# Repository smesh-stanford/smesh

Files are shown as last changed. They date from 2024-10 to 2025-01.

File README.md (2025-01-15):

# What is SMesh?
___
SMesh is a sensor mesh network ("smesh") that performs long duration environmental sensing for sustainability research at Stanford.

A smesh node (or "snode") consists of a sensor payload plus a Meshtastic board that can relay readings using long range LoRa radio.

# Customizing Meshtastic firmware
___
Snodes run a stable version of Meshtastic firmware with small modifications.

To access this firmware:
1. Clone the firmware fork, i.e. `git clone https://github.com/josdo/meshtastic-firmware.git`
2. Follow https://meshtastic.org/docs/development/firmware/build/ to set up PlatformIO, a tool to build firmware from source. 
   **Note:** at step 3, pick `heltec-v3` from the list of options given.

# SMesh - Raspberry Pi Setup Guide
___

## Install Raspberry Pi OS on SD Card

1. Go to: [Raspberry Pi Software](https://www.raspberrypi.com/software/)
2. Download and install **Raspberry Pi Imager**.
3. Insert your SD card into your computer or laptop.
4. Open **Raspberry Pi Imager**.
5. Click on the **CHOOSE OS** box, then select:
    - `Raspberry Pi OS (other)`
    - Scroll down and select: `Raspberry Pi OS (Legacy, 32-bit) Lite`
6. Click on the **CHOOSE STORAGE** box and select your SD card.
7. Click on the **Settings** icon in the bottom right corner, then follow the steps:
    - Set hostname to `smeshX` (where X represents the number of the current system).
    - Tick the **Enable SSH** box.
    - Set the username and password:
      - Username: `pi`
      - Password: `smesh`
    - Configure wireless LAN:
      - SSID: Name of your WiFi network
      - Password: Password of your WiFi network
      - Wireless LAN country: `US`
    - Click **SAVE**.
8. Click **WRITE** to begin writing the OS to the SD card.
9. Once the Raspberry Pi OS has been installed, remove the SD card from your computer and insert it into your Raspberry Pi.
10. Power the Raspberry Pi by connecting a micro USB cable to the **PWR IN** slot (connected to a battery pack or wall outlet).
11. A green LED should light up near the **PWR IN** slot to indicate that the Raspberry Pi is ON.

## Remotely Connect to Raspberry Pi via SSH

1. After a couple of minutes, the Raspberry Pi should be connected to your local WiFi network.
2. Ensure your computer/laptop is connected to the same network.
3. Open a Terminal and enter the command:
   ```
   ssh pi@smeshX.local
   ```
4. During the first SSH connection, you may get the following error:
5. If you see this error:
    - Go to your user folder on your computer/laptop.
    - Find a folder named `.ssh`.
    - Open the file named `known_hosts` and delete its content, then save.
    - Try connecting again with:
      ```
      ssh pi@smeshX.local
      ```
6. When asked "*Are you sure you want to continue connecting?*", enter: `yes`.
7. Enter the password: `smesh`.
8. Once you see the prompt starting with `pi@smeshX`, you have successfully connected to the Raspberry Pi via SSH.

## Install Software and Dependencies on Raspberry Pi

1. Once connected via SSH, start by running the following commands:
    ```
    sudo apt update
    sudo apt upgrade
    ```
2. Install Python **pip**:
    ```
    sudo apt install python3-pip
    ```
3. Install **Git**:
    ```
    sudo apt install git -y
    ```
4. Clone the project's GitHub repository:
    ```
    git clone https://github.com/smesh-stanford/smesh.git
    ```
5. Open a different Terminal and upload the `credential.json` file from your own local directory to the Raspberry Pi by entering the command:
    ```
    scp /local/path/to/credentials.json pi@smeshX.local: /home/pi/smesh/snode
    ```
    (e.g. if the credentials.json file is stored in your local Downloads directory: `scp ~/Downloads/credentials.json pi@smeshX.local: /home/pi/smesh/snode` , where X in smeshX represents the number of the current system).
6. Once the upload has been completed, close this Terminal and go back to the previous one (where the SSH connection to the Raspberry Pi was established).
7. Navigate to the `snode` directory:
    ```
    cd ./smesh/snode
    ```
8. Install required dependencies:
    ```
    pip3 install -r requirements.txt
    ```
9. Create a data directory:
    ```
    mkdir data
    ```
10. In its default stage, the code will store any upcoming data packet to this data directory (absolute path: `/home/pi/smesh/snode/data`). In some cases, the user may want to change the name of the data directory to help with data management. In such case, the path to the data directory needs to be changed in the **read_aqi.py, start_read_aqi.sh** and **upload_to_gdrive.py** scripts located in `/smesh/snode/scripts`:
    - **read_aqi.py:** From line 46 - 76, all the path arguments in the **log_to_csv()** function need to be changed to the new data directory path. For instance, if the user created a different data directory named *data_pepperwood*, all path arugments in the log_to_csv() function would be changed to: `f’/home/pi/smesh/snode/**data_pepperwood**/{nodeid}_bme688.csv’`
    - **start_read_aqi.sh:** Line 7, Change the path in the last line from `~/smesh/snode/**data**/read_aqi_stdouterr_log.txt` to the new data directory path (e.g., `~/smesh/snode/**data_pepperwood**/read_aqi_stdouterr_log.txt`)
    - **uploading_to_gdrive.py:** Change the path in ****Line 33 in the main function, to the new data directory path (e.g. `'/home/pi/smesh/snode/**data_pepperwood'**`)
11. Give execute permissions to the script **start_read_aqi.sh**:
    ```
    chmod +x ~/smesh/snode/scripts/start_read_aqi.sh
    ```
12. Open the cron table editor:
    ```
    crontab -e
    ```
13. Enter `1` to select the **nano** text editor.
14. Scroll to the bottom and add the following two lines (the number `5` in the second line indicates the time in minutes between uploads):
    ```
    @reboot ~/smesh/snode/scripts/start_read_aqi.sh
    */5 * * * * /usr/bin/python3 ~/smesh/snode/scripts/upload_to_gdrive.py
    ```
15. Press `Ctrl + X` to exit.
16. Type `Y` and press `Enter` to save changes.
17. Run the command:
    ```
    python3 read_aqi.py /dev/ttyUSB0
    ```
18. The Cron Unix-based job scheduler should now be active, running the `read_aqi.py` and `upload_to_gdrive.py` scripts to upload data to Google Drive.

## Troubleshooting Tips

- Restart the Cron Unix-based job scheduler:
  ```
  sudo service cron restart
  ```
- Check the status of the Cron Unix-based job scheduler:
  ```
  systemctl status cron
  ```

- Test the `read_aqi.py` script for errors:
  1. Navigate to the script directory:
     ```
     cd ~/smesh/snode/scripts/
     ```
  2. Run the script without providing a serial port:
     ```
     python3 read_aqi.py
     ```
  3. If the only error shown is similar to the following, it means all dependencies are correctly installed:
  4. Next, run the script with the USB0 port:
     ```
     python3 read_aqi.py /dev/ttyUSB0
     ```
  5. If you get an error indicating that the port cannot be found, reconnect the Meshtastic or reboot the Raspberry Pi:
     ```
     reboot
     ```
  6. After reboot, reconnect via SSH:
     ```
     ssh pi@smeshX.local
     ```
  7. Enter the password: `smesh`.

# Contributing
*Cutting Releases*
Releases will be formatted as "XX.YY.ZZ" with the following scheme: 
- XX: major feature release, breaking changes
- YY: minor feature change, new functions or classes 
- ZZ: patches, bug fixes, optimizations

*Pushing commits*
Create a new branch following "task/feature-name", "bug/bug-name" and so forth

A recommended workflow would be:
```
git stash
git checkout main
git pull
git checkout (your branch)
git stash pop
git rebase origin/main
Fix merge conflicts
git push —force-with-lease
```

Prior to merging a PR, be sure to squash your commits. One way to do this is to run `git rebase -i` and replace everything but the first commit message with `s` for squash as so:
```
pick abc123 Commit message 1
s def456 Commit message 2
s ghi789 Commit message 3
```

*Notes for Contributions*
- Before starting on some new big chunk of code, it it is optional but highly recommended to open an issue first
  to say "Hey, I think this idea X should be implemented and I'm starting work on it. My general plan is Y, any feedback
  is appreciated." This will allow other devs to potentially save you time by not accidentially duplicating work etc...
- Please do not check in files that don't have real changes
- Please do not reformat lines that you didn't have to change the code on
- We recommend using the [Visual Studio Code](https://platformio.org/install/ide?install=vscode) editor along with the ['Trunk Check' extension](https://marketplace.visualstudio.com/items?itemName=trunk.io) (In beta for windows, WSL2 for the linux version),
  because it automatically follows our indentation rules and its auto reformatting will not cause spurious changes to lines.
- If your PR fixes a bug, mention "fixes #bugnum" somewhere in your pull request description.
- If your other co-developers have comments on your PR please tweak as needed.
- Please also enable "Allow edits by maintainers".
- If your PR gets accepted you can request a "Contributor" role in the Meshtastic Discord

# Usage (depreciated)
___
`snode` is a Python package that contains all dependencies and code to read from snodes.

Files are organized into three directories:
1. One-off scripts go into `snode/scripts`
2. Reusable code that scripts can import go into `snode/snode`
3. Tests for reusable code go into `snode/tests`

To run any Python code:
1. Install Poetry by following https://python-poetry.org/docs/#installing-with-pipx
2. Enter the package you're using, e.g., `cd snode`
3. Install the Python dependencies the code needs, i.e., `poetry install`
4. Run a Python script, i.e., `poetry run python PATH/TO/SCRIPT.PY`

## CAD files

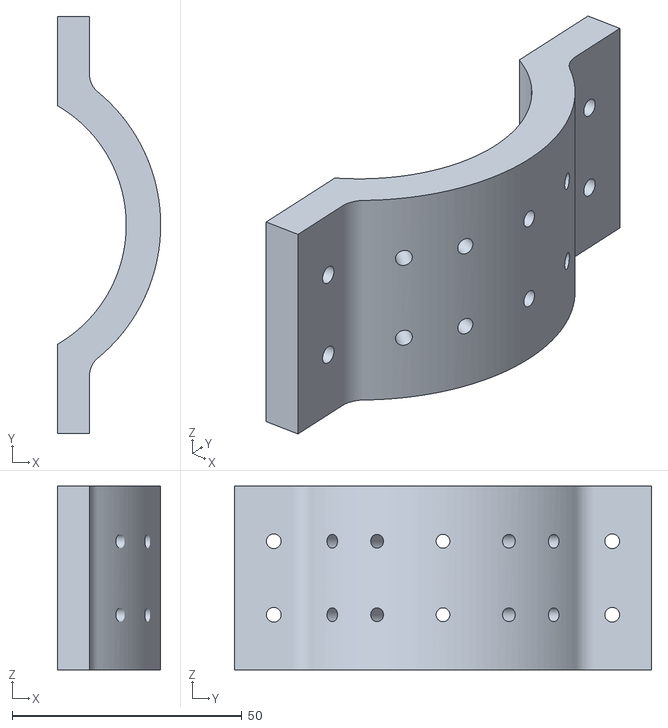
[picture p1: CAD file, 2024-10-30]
physical/mechanical/5.2-dome_and_holder/v5.2 - Enclosure only - Part 2.stl
22.5 x 90.7 x 40.0

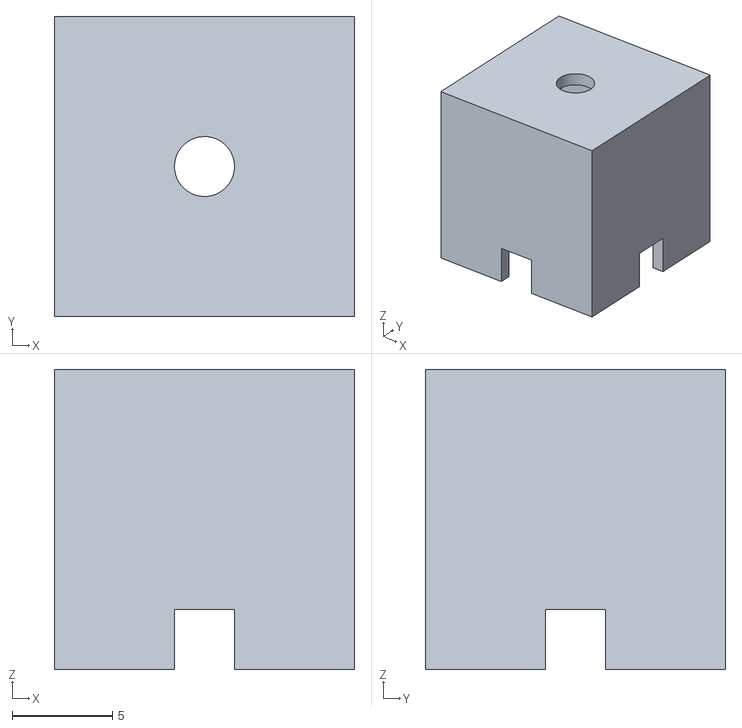
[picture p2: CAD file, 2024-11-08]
physical/mechanical/antennaholder.stl
15.0 x 15.0 x 15.0

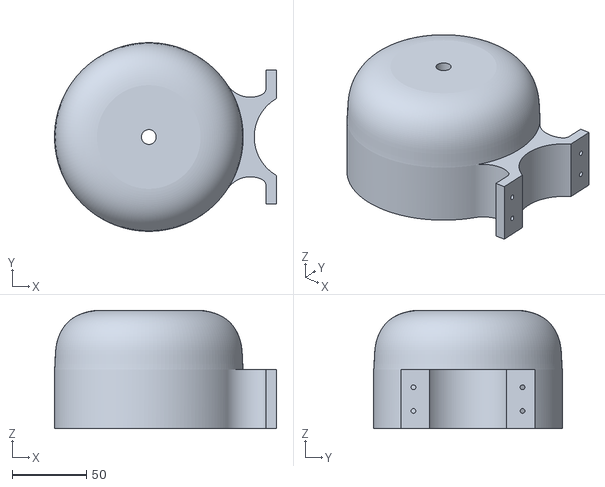
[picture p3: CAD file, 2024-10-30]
physical/mechanical/5.2-dome_and_holder/v5.2 - Enclosure only - Part 1.stl
149.9 x 127.4 x 80.0

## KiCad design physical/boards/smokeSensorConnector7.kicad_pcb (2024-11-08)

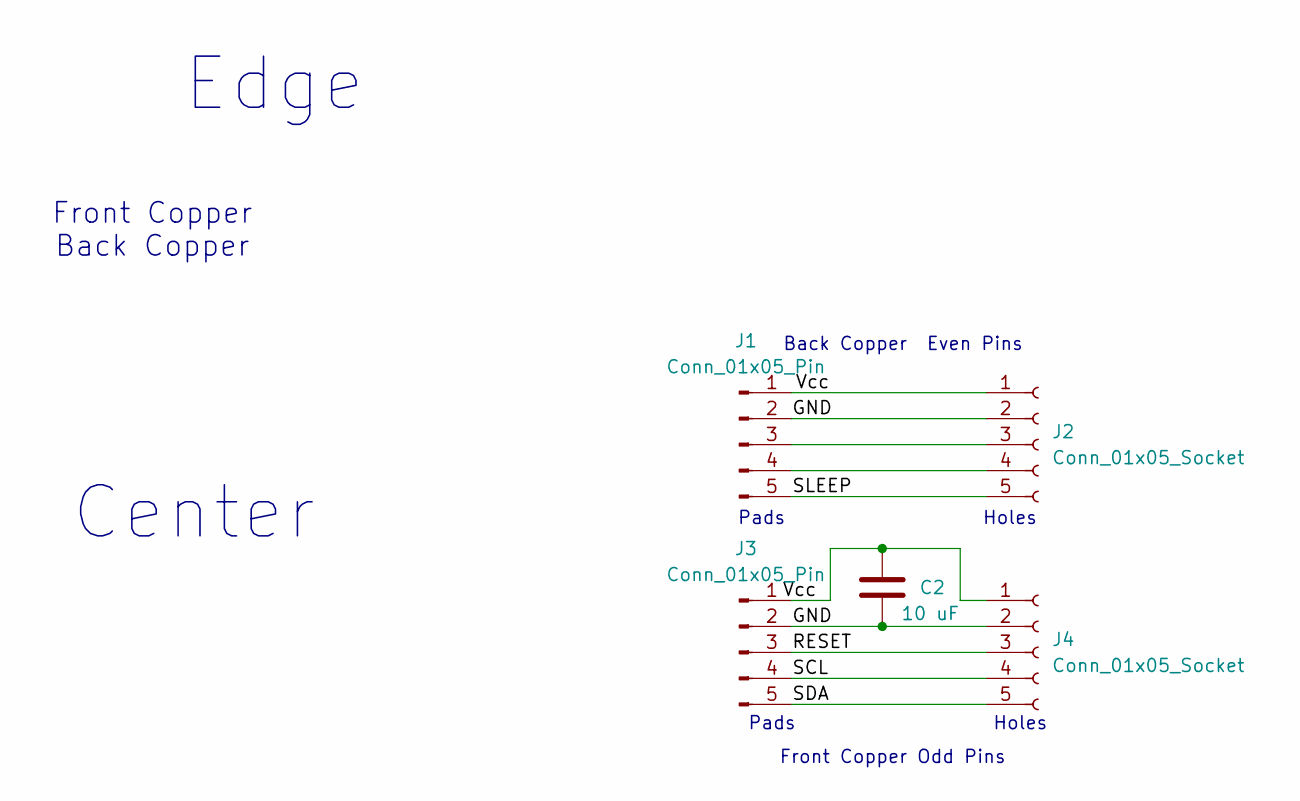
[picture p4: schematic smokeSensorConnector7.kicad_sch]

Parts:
C2: 10 uF; C_0805_2012Metric_Pad1.18x1.45mm_HandSolder
J1, J3: Conn_01x05_Pin; PinHeader_2x05_P1.00mm_Vertical_SMD
J2, J4: Conn_01x05_Socket; PinSocket_1x05_P2.54mm_Vertical

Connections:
/GND: C2.2, J1.2, J2.2, J3.2, J4.2
/RESET: J3.3, J4.3
/SCL: J3.4, J4.4
/SDA: J3.5, J4.5
/SLEEP: J1.5, J2.5
/Vcc: C2.1, J1.1, J2.1, J3.1, J4.1
unnamed: J1.3, J2.3
unnamed: J1.4, J2.4

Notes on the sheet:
Front Copper Back Copper
Center
Front Copper Odd Pins
Back Copper Even Pins
Pads Holes
Edge

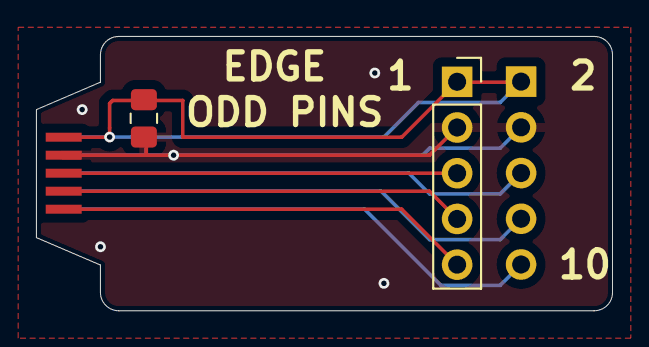
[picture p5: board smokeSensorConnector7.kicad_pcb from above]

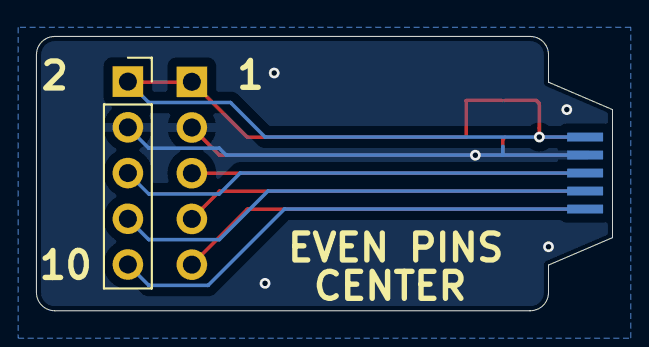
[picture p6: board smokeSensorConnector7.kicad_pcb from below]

Board: 2 copper layers, 32.0 x 15.2 mm, 5 parts (2 on the bottom side), 8 nets.

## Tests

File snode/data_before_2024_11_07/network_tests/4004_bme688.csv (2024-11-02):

2024-11-02 09:38:59.974664 | 0x336918e8 | 24.975153 | 40.520565 | 1011.9683 | 145.57863 | 227 | 7.0 | 5 | -65 | 5
2024-11-02 09:39:03.388706 | 0x433efcb4 | 25.741278 | 36.38869 | 1011.4799 | 676.77515 | 106 | 5.75 | 3 | -67 | 3
2024-11-02 09:39:06.332685 | 0x4358fbec | 27.327984 | 33.633705 | 1011.6007 | 446.09018 | 88 | 5.25 | 6 | -79 | 6
2024-11-02 09:39:20.301704 | 0x336918e8 | 24.970427 | 40.521217 | 1011.967 | 144.96036 | 226 | 6.0 | 5 | -69 | 5
2024-11-02 09:39:24.892501 | 0x433efcb4 | 25.711206 | 36.434563 | 1011.4597 | 671.3446 | 106 | 5.5 | 3 | -69 | 3
2024-11-02 09:39:27.791551 | 0x4358fbec | 27.33014 | 33.686333 | 1011.58966 | 452.2968 | 82 | -0.5 | 6 | -90 | 6
2024-11-02 09:39:41.247261 | 0x336918e8 | 24.986933 | 40.43119 | 1011.96765 | 146.32751 | 224 | 5.5 | 5 | -69 | 5
2024-11-02 09:39:46.342864 | 0x4358fbec | 27.337856 | 33.654846 | 1011.60394 | 452.89694 | 83 | 4.75 | 6 | -79 | 6
2024-11-02 09:39:58.002227 | 0x433efcb4 | 25.603674 | 36.604164 | 1011.44507 | 666.66394 | 108 | 5.75 | 3 | -63 | 3
2024-11-02 09:40:01.026133 | 0x336918e8 | 25.001318 | 40.382744 | 1011.9892 | 148.23393 | 222 | 5.75 | 5 | -67 | 5
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

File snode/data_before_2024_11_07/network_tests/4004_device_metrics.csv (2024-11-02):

2024-11-02 09:38:54.542882 | 0x4358fbec | 101 | 4.239 | 24.126667 | 6.0195556 | 6.25 | 6 | -71 | 6
2024-11-02 09:39:35.419871 | 0x33644004 | 101 | 4.209 | 21.33 | 0.051333338 |  | 6 |  | 6
2024-11-02 09:40:31.146955 | 0x433efcb4 | 101 | 4.236 | 21.776667 | 5.756778 | 5.5 | 3 | -70 | 3
2024-11-02 09:40:35.449356 | 0x33644004 | 101 | 4.215 | 20.761667 | 0.11272222 |  | 6
2024-11-02 09:41:29.808206 | 0x336918e8 | 101 | 5.14 | 22.278332 | 3.3621664 | 5.0 | 5 | -74 | 5
2024-11-02 09:41:33.518703 | 0x433efcb4 | 100 | 4.19 | 22.965 | 5.756778 | 5.5 | 3 | -64 | 3
2024-11-02 09:41:35.576283 | 0x33644004 | 101 | 4.232 | 21.786667 | 0.14400001 |  | 6
2024-11-02 09:42:35.574146 | 0x33644004 | 101 | 4.204 | 30.596668 | 0.27727777 |  | 6
2024-11-02 09:43:34.235770 | 0x433efcb4 | 100 | 4.197 | 23.966667 | 5.678 | 5.5 | 3 | -71 | 3
2024-11-02 09:43:35.708284 | 0x33644004 | 101 | 4.236 | 29.716667 | 0.32155555 |  | 6
2024-11-02 09:44:35.569759 | 0x43590ff4 | 100 | 4.199 | 23.83 | 5.544083 | 5.25 | 5 | -74 | 5
2024-11-02 09:44:35.840091 | 0x33644004 | 101 | 4.213 | 28.906668 | 0.4722222 |  | 6
2024-11-02 09:45:35.682924 | 0x33644004 | 101 | 4.22 | 37.41333 | 0.5910278 |  | 6
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

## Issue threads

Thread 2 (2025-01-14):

Separate `Dashboard` and `Physical` to new repositories

danineamati, 2025-01-14:
The current `smesh` repo should probably only contain (1) the firmware and (2) the logging software (arguably, even these should be separate repositories). The `dashboard` code should be a separate repository and may benefit from adding https://github.com/smesh-stanford/smesh_visualization as a dependency. The `physical` files (i.e., PCB and 3D printing files) will not interact with the firmware or logging code and can either be a separate repository or just on Google Drive.

lfun1, 2025-01-25:
GitHub Repo Reorganization:
- Transferred dashboard folder to [smesh_dashboard](https://github.com/smesh-stanford/smesh_dashboard) repo
    - Added smesh_visualization as dependency to smesh_dashboard using git submodules
    - See this [Linked Dependency Post](https://stackoverflow.com/questions/7813030/how-can-i-have-linked-dependencies-in-a-git-repo) for instructions on how to update dependencies
        - `git submodule init`, `git submodule update` for your existing dependency version
        - `cd visualization`, `git pull` to update dependency version
- Moved physical folder to Google Drive [physical folder](https://drive.google.com/drive/folders/1TcDmi7lHw6MQ5zjq9wXfqhfcP2IxHO2b?usp=drive_link) in smesh-mechanical folder
- Firmware and logging (snode) kept in original smesh repo

danineamati, 2025-01-29:
Looks great to me! Do you want to include the submodule context in the readme in the `smesh_dashboard` repo?

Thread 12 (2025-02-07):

Notification of Snode Being Down

yumibyte, 2025-02-07:
# CONTEXT
This is an open ended, cute and cool additional feature. It would be interesting to receive a notification (e.g. slack) when a Snode is "down." This downage can be determined by the logs from the snode and also based off of any errors provided in the log (e.g. watchdog timer error).

Some requirements would be:
- Notation of which node is down
- Perhaps a clip of the log which triggered this notification
- Ensuring this notification is not "spammed"

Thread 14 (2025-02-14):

Setup LED to be configured on initialize.sh

yumibyte, 2025-02-14:
# CONTEXT
We want to be able to configure the LED on the Raspberry Pi to display multiple colors via a neopixel for more specific error logging. Talk to Pete! Refer to this document: https://drive.google.com/file/d/1JKwW2ykTD3mngxr49Tp5c5CxWLDgQb8F/view

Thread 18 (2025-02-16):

Adjust firstrun such that initialize_rpi.sh passes parameters and can execute

yumibyte, 2025-02-16:
# CONTEXT
- The current script doesn't function with `firstrun.sh` and appears to not run the `initialize_rpi.sh` script. As a part of this issue we should tackle passing the proper passwords and names to the `initialize_rpi.sh` script. Therefore, this issue tackles how to configure the rpi from the first initialization "all in one go."

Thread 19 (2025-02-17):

Setting the relevant SNode intervals

danineamati, 2025-02-17:
## Background
The Meshtastic configuration is stored in a yaml file, such as https://github.com/smesh-stanford/smesh/blob/main/firmware/build_standard_1.0.yaml. However, some of the intervals are based on (limited) field data, and some are set by default. The intervals for the sensors have been set with some domain knowledge in mind. The most recent settings are in https://github.com/smesh-stanford/smesh/blob/main/firmware/build_1_config.yaml.

## Questions

1. However, the `nodeInfoBroadcastSecs` is set at `10800` by default. What should this be set at and why?
3. Can we better set the sensor intervals using frequency space analysis of the data we already have?

## Helpful references

### Documentation
Documentation information: https://meshtastic.org/docs/overview/mesh-algo/#regular-broadcast-intervals

### Meshtastic Configuration
Command to export the config file from meshtastic device to computer:
```
meshtastic --export-config > example_config.yaml
```
(depending on path, `python -m meshtastic` may be more reliable)

Command to import the config file from computer to meshtastic device:
```
meshtastic --configure example_config.yaml
```

### Example observed field data intervals

Pepperwood:
- Air Quality (60 sec): https://github.com/smesh-stanford/smesh_visualization/blob/main/plots/pepperwood-post-burn/62e4/full_timeseries/pmsa003i_sensor_interval_boxplot_bound_50-70s.png
- Device Metrics (360 sec): https://github.com/smesh-stanford/smesh_visualization/blob/main/plots/pepperwood-post-burn/62e4/full_timeseries/device_metrics_sensor_interval_boxplot_bound_330-390s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
- Environmental (60 sec): https://github.com/smesh-stanford/smesh_visualization/blob/main/plots/pepperwood-post-burn/62e4/full_timeseries/bme688_sensor_interval_boxplot_bound_50-70s.png
- Power (300 sec): https://github.com/smesh-stanford/smesh_visualization/blob/main/plots/pepperwood-post-burn/62e4/full_timeseries/ina260_sensor_interval_boxplot_bound_270-330s.png

Burn Bot (note links point to branch, not main):
- Air Quality (60 sec): https://github.com/smesh-stanford/smesh_visualization/blob/external-data/plots/burnbot-post-burn/4004/full_timeseries/pmsa003i_sensor_interval_boxplot_bound_50-140s.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
- Device Metrics (360 sec): https://github.com/smesh-stanford/smesh_visualization/blob/external-data/plots/burnbot-post-burn/4004/full_timeseries/device_metrics_sensor_interval_boxplot_bound_33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
- Environmental (60 or 180 sec): https://github.com/smesh-stanford/smesh_visualization/blob/external-data/plots/burnbot-post-burn/4004/full_timeseries/bme688_sensor_interval_boxplot_bound_50-200s.pn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
- Power (300 or 600 sec): https://github.com/smesh-stanford/smesh_visualization/blob/external-data/plots/burnbot-post-burn/4004/full_timeseries/ina260_sensor_interval_boxplot_bound_270-630s.p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

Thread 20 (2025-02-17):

Testing the initialize RPi script with hardware in the loop

danineamati, 2025-02-17:
## Context
In PR #17, we added the `initialize_rpi.sh` script to set up the Raspberry Pi as a "SMesh Logger Raspberrry Pi." While we did verify that it works on the software side, there may be some hardware-in-the-loop checks that may be worthwhile to verify before any field deployment.

⚠ _Please document throughout with screenshots and images!_

## Hardware needed for checks
- Real-Time Clock (RTC) with clock battery
- "Normal" Meshtastic Radio
- Mobile device (ideally both iOS and Android devices)
- Laptop with Raspberry Pi Imager
- Presence in Packard

## Code snips separated by Hardware-in-the-loop checks
- [x] Can connect to wifi automatically (e.g., EE-IoT): https://github.com/smesh-stanford/smesh/blob/d5a541cff879ac5890c1ad75927a494ffb5df7c3/snode/scripts/initialize_rpi.sh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
    - Verified 16 Feb from the third-floor bridge over the atrium. **Have we tested this from a fresh Pi Image?**
- [ ] Connects to Real Time Clock: https://github.com/smesh-stanford/smesh/blob/d5a541cff879ac5890c1ad75927a494ffb5df7c3/snode/scripts/initialize_rpi.sh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
- [ ] Verify that the swap is set correctly: https://github.com/smesh-stanford/smesh/blob/d5a541cff879ac5890c1ad75927a494ffb5df7c3/snode/scripts/initialize_rpi.sh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
- [ ] Meshtastic radio gets properly configured: https://github.com/smesh-stanford/smesh/blob/d5a541cff879ac5890c1ad75927a494ffb5df7c3/snode/scripts/initialize_rpi.sh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
- [ ] Commands are correctly added to `cron` and are run at reboot (i.e., rather than immediately): https://github.com/smesh-stanford/smesh/blob/d5a541cff879ac5890c1ad75927a494ffb5df7c3/snode/scripts/initialize_rpi.sh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
- [x] SSH to pi is functional through pi hotspot: https://github.com/smesh-stanford/smesh/blob/d5a541cff879ac5890c1ad75927a494ffb5df7c3/snode/scripts/initialize_rpi.sh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
    - Verified 16 Feb using the Terminus App on Pixel 6a. **Have we tested on an iOS device?**

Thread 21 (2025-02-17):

Add Google Drive upload to cron at initialize

danineamati, 2025-02-17:
### Context
Currently, the `initialize_rpi.sh` script adds the _logging_ to the cron, but it does not add the Google Drive upload to the cron.

https://github.com/smesh-stanford/smesh/blob/d5a541cff879ac5890c1ad75927a494ffb5df7c3/snode/scripts/initialize_rpi.sh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

### Suggested fix
Use the `routine_upload_gdrive.sh` bash script as an example to set up the cron. https://github.com/smesh-stanford/smesh/blob/d5a541cff879ac5890c1ad75927a494ffb5df7c3/snode/scripts/routine_upload_gdrive.sh

⚠ You will need authentication information from Jessica to successfully upload to Google Drive.

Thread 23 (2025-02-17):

Deprecating old logger scripts

danineamati, 2025-02-17:
We have a few scripts that are no longer in use and should be deprecated. We may not want to delete them outright until we have a more reliable logger.

- [ ] 🐍  `log_telemetry.py` (`rpi_log_script.py` is the new version): https://github.com/smesh-stanford/smesh/blob/d5a541cff879ac5890c1ad75927a494ffb5df7c3/snode/scripts/log_telemetry.py
- [ ] 🐍 `network_test.py` (`rpi_log_script.py` is the new version): https://github.com/smesh-stanford/smesh/blob/d5a541cff879ac5890c1ad75927a494ffb5df7c3/snode/scripts/network_test.py
- [ ] 🐍 `read_aqi.py` (`rpi_log_script.py` is the new version): https://github.com/smesh-stanford/smesh/blob/d5a541cff879ac5890c1ad75927a494ffb5df7c3/snode/scripts/read_aqi.py
    - ⚠ `read_aqi.py` is the most reliable logging script thus far and was the only one that seemed to fully work at BurnBot (rationale unclear)
- [ ] 🏗  `start_network_read_aqi.sh` (`initialize_rpi.sh` now sets the python file in cron directly AND `network_test.py` is to be deprecated above): https://github.com/smesh-stanford/smesh/blob/d5a541cff879ac5890c1ad75927a494ffb5df7c3/snode/scripts/start_network_read_aqi.sh
- [ ] 🏗  `start_read_aqi.sh` (`initialize_rpi.sh` now sets the python file in cron directly AND `read_aqi.py` is to be deprecated above): https://github.com/smesh-stanford/smesh/blob/d5a541cff879ac5890c1ad75927a494ffb5df7c3/snode/scripts/start_read_aqi.sh
- [ ] 🏗  `start_rpi_log.sh` (`initialize_rpi.sh` now sets the python file in cron directly): https://github.com/smesh-stanford/smesh/blob/d5a541cff879ac5890c1ad75927a494ffb5df7c3/snode/scripts/start_rpi_log.sh
- [ ] 🏗  `routine_upload_gdrive.sh` (`initialize_rpi.sh` should include this code; see Issue #21): https://github.com/smesh-stanford/smesh/blob/d5a541cff879ac5890c1ad75927a494ffb5df7c3/snode/scripts/routine_upload_gdrive.sh

Remaining scripts (not deprecated):
🔝 signals most recently updated
- 🔝  🐍 `rpi_log_script.py` runs the Python script to log the Meshtastic data: https://github.com/smesh-stanford/smesh/blob/d5a541cff879ac5890c1ad75927a494ffb5df7c3/snode/scripts/rpi_log_script.py
- 🔝 🏗 `initialize_rpi.sh` initializes the Pi and sets the corn: https://github.com/smesh-stanford/smesh/blob/d5a541cff879ac5890c1ad75927a494ffb5df7c3/snode/scripts/initialize_rpi.sh
- 🐍 `serial_log.py` shows everything on the USB serial connection, which is helpful for debugging a new sensor (e.g., the LARK and PAWS wind sensors). https://github.com/smesh-stanford/smesh/blob/d5a541cff879ac5890c1ad75927a494ffb5df7c3/snode/scripts/serial_log.py
- 🏗 `traceroute_test.sh` has an example code for tracing the mesh route, but it needs to be updated; see Issue #22). https://github.com/smesh-stanford/smesh/blob/d5a541cff879ac5890c1ad75927a494ffb5df7c3/snode/scripts/traceroute_test.sh
- 🐍 `upload_to_gdrive.py` runs the python to push the data to Google Drive. https://github.com/smesh-stanford/smesh/blob/d5a541cff879ac5890c1ad75927a494ffb5df7c3/snode/scripts/upload_to_gdrive.py

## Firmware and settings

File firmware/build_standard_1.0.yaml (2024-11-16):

config:
    bluetooth:
        enabled: true
        fixedPin: 336710
        mode: FIXED_PIN
    device:
        nodeInfoBroadcastSecs: 10800
        serialEnabled: true
    display:
        screenOnSecs: 600
    lora:
        channelNum: 104
        frequencyOffset: 0.05
        hopLimit: 5
        region: US
    telemetry:
        airQualityEnabled: true
        airQualityInterval: 30
        deviceUpdateInterval: 360
        environmentMeasurementEnabled: true
        environmentUpdateInterval: 60
        powerMeasurementEnabled: true
        powerUpdateInterval: 300

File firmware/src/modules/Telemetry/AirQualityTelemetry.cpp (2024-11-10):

#include "configuration.h"

#if !MESHTASTIC_EXCLUDE_ENVIRONMENTAL_SENSOR

#include "../mesh/generated/meshtastic/telemetry.pb.h"
#include "AirQualityTelemetry.h"
#include "Default.h"
#include "MeshService.h"
#include "NodeDB.h"
#include "PowerFSM.h"
#include "RTC.h"
#include "Router.h"
#include "detect/ScanI2CTwoWire.h"
#include "main.h"
#include <Throttle.h>

int32_t AirQualityTelemetryModule::runOnce()
{
    /*
        Uncomment the preferences below if you want to use the module
        without having to configure it from the PythonAPI or WebUI.
    */

    moduleConfig.telemetry.air_quality_enabled = 1;
    moduleConfig.telemetry.air_quality_interval = 3;

    if (!(moduleConfig.telemetry.air_quality_enabled)) {
        // If this module is not enabled, and the user doesn't want the display screen don't waste any OSThread time on it
        return disable();
    }

    if (firstTime) {
        // This is the first time the OSThread library has called this function, so do some setup
        firstTime = false;

        if (moduleConfig.telemetry.air_quality_enabled) {     
            LOG_INFO("Air quality Telemetry: Initializing");
            if (!aqi.begin_I2C(&Wire1)) {
                LOG_WARN("Could not establish i2c connection on peripheral bus");
                return disable();
            }
            // Look for the Sensor
            uint8_t i2caddr_scan[] = {PMSA0031_ADDR};
            uint8_t i2caddr_asize = 1;
            auto i2cScanner = std::unique_ptr<ScanI2CTwoWire>(new ScanI2CTwoWire());
            i2cScanner->scanPort(ScanI2C::I2CPort::WIRE1, i2caddr_scan, i2caddr_asize);
            auto found = i2cScanner->find(ScanI2C::DeviceType::PMSA0031);
            if (found.type != ScanI2C::DeviceType::NONE) {
                nodeTelemetrySensorsMap[meshtastic_TelemetrySensorType_PMSA003I].first = found.address.address;
                nodeTelemetrySensorsMap[meshtastic_TelemetrySensorType_PMSA003I].second =
                    i2cScanner->fetchI2CBus(found.address);
                return (1000);
                }
            uint16_t try_again = 1000;
            while (try_again--) {
                LOG_WARN("Could not establish i2c connection to AQI sensor. Rescanning...");
                if (found.type != ScanI2C::DeviceType::NONE) {
                    nodeTelemetrySensorsMap[meshtastic_TelemetrySensorType_PMSA003I].first = found.address.address;
                    nodeTelemetrySensorsMap[meshtastic_TelemetrySensorType_PMSA003I].second =
                        i2cScanner->fetchI2CBus(found.address);
                    return (1000);
                    }
                }
            LOG_WARN("Could not establish i2c connection to AQI sensor.");
            return disable();
        }
        } else {
        // if we somehow got to a second run of this module with measurement disabled, then just wait forever
        if (!moduleConfig.telemetry.air_quality_enabled)
            return disable();

        if (((lastSentToMesh == 0) ||
             !Throttle::isWithinTimespanMs(lastSentToMesh, 3000))){
            //  Default::getConfiguredOrDefaultMsScaled(
            //        moduleConfig.telemetry.air_quality_interval,
            //        default_telemetry_broadcast_interval_secs, numOnlineNodes))) &&
            // airTime->isTxAllowedChannelUtil(config.device.role != meshtastic_Config_DeviceConfig_Role_SENSOR) &&
            // airTime->isTxAllowedAirUtil()) {
            sendTelemetry();
            lastSentToMesh = millis();
        } else if (service->isToPhoneQueueEmpty()) {
            // Just send to phone when it's not our time to send to mesh yet
            // Only send while queue is empty (phone assumed connected)
            sendTelemetry(NODENUM_BROADCAST, true);
        }
    }
    return sendToPhoneIntervalMs;
}

bool AirQualityTelemetryModule::handleReceivedProtobuf(const meshtastic_MeshPacket &mp, meshtastic_Telemetry *t)
{
    if (t->which_variant == meshtastic_Telemetry_air_quality_metrics_tag) {
#ifdef DEBUG_PORT
        const char *sender = getSenderShortName(mp);

        LOG_INFO("(Received from %s): pm10_standard=%i, pm25_standard=%i, pm100_standard=%i", sender,
                 t->variant.air_quality_metrics.pm10_standard, t->variant.air_quality_metrics.pm25_standard,
                 t->variant.air_quality_metrics.pm100_standard);

        LOG_INFO("                  | PM1.0(Environmental)=%i, PM2.5(Environmental)=%i, PM10.0(Environmental)=%i",
                 t->variant.air_quality_metrics.pm10_environmental, t->variant.air_quality_metrics.pm25_environmental,
                 t->variant.air_quality_metrics.pm100_environmental);
#endif
        // release previous packet before occupying a new spot
        if (lastMeasurementPacket != nullptr)
            packetPool.release(lastMeasurementPacket);

        lastMeasurementPacket = packetPool.allocCopy(mp);
    }

    return false; // Let others look at this message also if they want
}

bool AirQualityTelemetryModule::getAirQualityTelemetry(meshtastic_Telemetry *m)
{
    if (!aqi.read(&data)) {
        LOG_WARN("Skipping send measurements. Could not read AQIn");
        return false;
    }

    m->time = getTime();
    m->which_variant = meshtastic_Telemetry_air_quality_metrics_tag;
    m->variant.air_quality_metrics.pm10_standard = data.pm10_standard;
    m->variant.air_quality_metrics.pm25_standard = data.pm25_standard;
    m->variant.air_quality_metrics.pm100_standard = data.pm100_standard;

    m->variant.air_quality_metrics.pm10_environmental = data.pm10_env;
    m->variant.air_quality_metrics.pm25_environmental = data.pm25_env;
    m->variant.air_quality_metrics.pm100_environmental = data.pm100_env;

    LOG_INFO("(Sending): PM1.0(Standard)=%i, PM2.5(Standard)=%i, PM10.0(Standard)=%i",
             m->variant.air_quality_metrics.pm10_standard, m->variant.air_quality_metrics.pm25_standard,
             m->variant.air_quality_metrics.pm100_standard);

    LOG_INFO("         | PM1.0(Environmental)=%i, PM2.5(Environmental)=%i, PM10.0(Environmental)=%i",
             m->variant.air_quality_metrics.pm10_environmental, m->variant.air_quality_metrics.pm25_environmental,
             m->variant.air_quality_metrics.pm100_environmental);

    return true;
}
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

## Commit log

2024-10-30 added dome + holder cad
    [v5.2 - Enclosure only - Part 1.stl, v5.2 - Enclosure only - Part 2.stl]
2024-11-01 4004 logging from afcc range tests 10-31-2024
    [4004_bme688.csv, 4004_device_metrics.csv, 4004_ina260.csv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]
2024-11-02 Network test script and data on 11/2/24
    [4004_bme688.csv, 4004_device_metrics.csv, 4004_ina260.csv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]
2024-11-02 Network test update data
    [4004_bme688.csv, 4004_pmsa003i.csv]
2024-11-05 corrected paths to data directory in read_aqi.py
    [read_aqi.py]
2024-11-06 replaced paths in read_aqi.py with absolute paths
    [read_aqi.py]
2024-11-08 Reorganize GitHub folder structure
    [antennaholder.stl, smokeSensorConnector7.kicad_pcb, smokeSensorConnector7.kicad_sch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]
2024-11-08 Reorganize data, improve log telemetry script from read aqi
    [4004_bme688.csv, 4004_device_metrics.csv, 4004_ina260.csv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]
2024-11-08 Add basic web dashboard framework
    [4004_pmsa003i.csv]
2024-11-08 Fix signal strength logging order
    [log_telemetry.py]
2024-11-10 Add Meshtastic firmware v2.5.12
    [.isort.cfg, configuration.h, partition-table.csv]
2024-11-10 Add updated Air Quality Telemetry for PMS sensor
2024-12-06 Add Serial log script for Wind sensor attached to Raspberry Pi
2024-12-07 Update upload_to_gdrive.py
    Skip *.txt files in the directory
    [upload_to_gdrive.py]
2024-12-17 Raspberry Pi logging script with datetime appended to log files, after Henry Coe burn
2024-12-17 Running Raspberry Pi logging script from Packard reader v1
    [0ff4_device_metrics_2024-12-16 19:33:02.808968.csv, 0ff4_device_metrics_2024-12-16 20:33:35.365606.csv]
2024-12-17 Delete snode/data/0ff4_device_metrics_2024-12-16 19:33:02.808968.csv
    Delete due to file name issue with colon in datetime
    [0ff4_device_metrics_2024-12-16 19:33:02.808968.csv]
2024-12-17 Delete snode/data/0ff4_device_metrics_2024-12-16 20:33:35.365606.csv
    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
    [0ff4_device_metrics_2024-12-16 20:33:35.365606.csv]
2024-12-17 Resolve issues with telemetry_key argument passing
    [0ff4_device_metrics_2024-12-16 23:03:41.601366.csv]
2024-12-17 Cleanup phase 4 of RPi logging script - resolve headers, clean up code, reformat stdout
    [0ff4_deviceMetrics_2024-12-16 23_23_58.977614.csv, 0ff4_deviceMetrics_2024-12-16 23_28_59.702367.csv, 0ff4_device_metrics_2024-12-16 23:03:41.601366.csv]
2024-12-17 Necessary datetime prints for upload
    Without the datetime prints it is practically impossible to know when commands were run.
2024-12-17 Thread safety for telemetry logs
    [62e4_pmsa003i.csv]
2024-12-17 Data from Packard 302 with v2 logger
    [0ff4_airQualityMetrics_2024-12-17 07_37_01.158597.csv, 0ff4_airQualityMetrics_2024-12-17 08_37_03.775008.csv, 0ff4_airQualityMetrics_2024-12-17 09_37_06.694274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]
2024-12-17 First data from v3
    [0ff4_airQualityMetrics_2024-12-17_15-09-49.csv, 0ff4_deviceMetrics_2024-12-17_15-09-49.csv, 0ff4_environmentMetrics_2024-12-17_15-09-49.csv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]
2024-12-18 Add data from v3 raspberry pi logging
    [0ff4_airQualityMetrics_2024-12-17_15-52-53.csv, 0ff4_deviceMetrics_2024-12-17_15-52-53.csv, 0ff4_environmentMetrics_2024-12-17_15-52-53.csv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]
2024-12-18 Move data and heard from counter
    [0ff4_airQualityMetrics_2024-12-17 07_37_01.158597.csv, 0ff4_airQualityMetrics_2024-12-17 08_37_03.775008.csv, 0ff4_airQualityMetrics_2024-12-17 09_37_06.694274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]
2024-12-18 Move recent files back to prevent merge conflict
    [0ff4_airQualityMetrics_2024-12-17_15-52-53.csv, 0ff4_deviceMetrics_2024-12-17_15-52-53.csv, 0ff4_environmentMetrics_2024-12-17_15-52-53.csv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]
2024-12-18 filename changes to avoid merge issue.
    [0ff4_airQualityMetrics_2024-12-17_15-52-53.csv, 0ff4_airQualityMetrics_2024-12-17_15-52-53_v3.csv, 0ff4_deviceMetrics_2024-12-17_15-52-53.csv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]
2024-12-18 Threading name check
2024-12-18 data before thread check
    [0ff4_airQualityMetrics_2024-12-17_16-52-29.csv, 0ff4_deviceMetrics_2024-12-17_16-52-29.csv, 0ff4_environmentMetrics_2024-12-17_16-52-29.csv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]
2024-12-18 Show active threads
2024-12-18 data with initial thread prints
    [0ff4_airQualityMetrics_2024-12-17_17-24-43.csv, 0ff4_deviceMetrics_2024-12-17_17-24-43.csv, 0ff4_environmentMetrics_2024-12-17_17-24-43.csv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]
2024-12-18 More verbose thread printing
2024-12-18 Add thread print verbosity in main
2024-12-18 Data with thread prints
    [0ff4_airQualityMetrics_2024-12-17_17-35-10.csv, 0ff4_deviceMetrics_2024-12-17_17-35-10.csv, 0ff4_environmentMetrics_2024-12-17_17-35-10.csv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]
2024-12-18 Print lock information
2024-12-18 Data from printing with active threads from start
    [0ff4_airQualityMetrics_2024-12-17_17-59-28.csv, 0ff4_airQualityMetrics_2024-12-17_17-59-55.csv, 0ff4_deviceMetrics_2024-12-17_17-59-28.csv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]
2024-12-18 Better lock printing
2024-12-18 more data from thread printing
    [0ff4_airQualityMetrics_2024-12-17_18-08-24.csv, 0ff4_deviceMetrics_2024-12-17_18-08-24.csv, 0ff4_environmentMetrics_2024-12-17_18-08-24.csv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]
2024-12-18 Evening 12/17 push data and logs
    [0ff4_airQualityMetrics_2024-12-17_18-24-41.csv, 0ff4_airQualityMetrics_2024-12-17_18-31-04.csv, 0ff4_airQualityMetrics_2024-12-17_19-31-05.csv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]
2024-12-18 Pre-burn-bot node configs
    [c2b0_airQualityMetrics_2024-12-18_11-18-04.csv, c2b0_deviceMetrics_2024-12-18_11-18-04.csv, c2b0_environmentMetrics_2024-12-18_11-18-04.csv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]
2024-12-18 Checking 0b38 logging
    [0b38_airQualityMetrics_2024-12-18_11-53-45.csv, 0b38_deviceMetrics_2024-12-18_11-53-45.csv, 0b38_environmentMetrics_2024-12-18_11-53-45.csv]
2024-12-29 Add updated RPi logging script post-BurnBot with file lock timeout, try/except blocks to catch general exceptions, watch dog timer (WDT) and pub resubscribe recovery, and counting nodes heard from
    [rpi_log_script_v4.py]
